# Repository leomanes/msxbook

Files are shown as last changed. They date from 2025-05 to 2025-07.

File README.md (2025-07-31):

# Msxbook side slot
(Msxbook external slot 2 adapter)

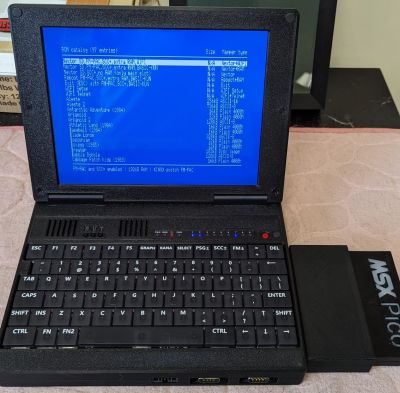
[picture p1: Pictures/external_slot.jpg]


You are welcome to make and sell the adapter to the MSX community if you agree not to change the original files. 
Don't add new text or logos... don't change anything at all and it is all good.

Parts List:

-Main PCB: \
-- F1: 125ma to 375ma fuse (-12v line) \
-- F2: 800ma to 1A fuse (+5v line) \
-- F3: 400ma to 500ma fuse (+12v line) \
-- J1: 2x25 right angle pin header \
-- J2: 50 pin right angle male SCSI connector

***  The fuses are optional but recomended. If you don't want to use them, use a solid wire (old network cables are good donors).

-External PCB: \
-- C1: 100uf to 220uf 25v (optional)\
-- C2: 100uf to 220uf 25v (optional)\
-- C3: 220uf to 470uf 16v (optional)\
-- J1: 50 pin right angle edge connector\
-- J2: 50 pin right angle female SCSI connector

-3D brackets: (The dimentions below are critical. Get the correct ones.) \
--Screws are M2.5 x 5mm\
--Inserts are M2.5 x 2.5 x 3.5 

-Parts Link: \
https://a.aliexpress.com/_mOBWXzN \
https://www.aliexpress.us/item/2255800960638500.html (option: 2X25 50PIN) \
https://www.aliexpress.com/item/3256808357131162.html (option: M2.5x2.5x3.5) \
SCSI connectors: single or pack \
https://www.aliexpress.us/item/3256807779614080.html (option: 50 pin curved female and 50 pin curved male) \
https://a.aliexpress.com/_mt0LCd1 (option: 50 pin curved female and 50 pin curved male)

Tips and tricks: \
*** When soldering the EDGE connector, make sure the distance between the PCB and the connector is between 2mm and 3mm. \
*** The distance between the bottom of the main PCB and the top ot the angled pin header needs to be 7.3mm \
*** Make sure the angled pin header and EDGE connectors are at a nice 90°. Start by solderins pins 1, 2 and 49, 50 and then do a fit test and measure the distance mentioned above. \
*** To insert the pcb into the 3D cart, angle it 45° and insert the left side first ("left" when looking at inside the EDGE where the cart connects) then slide the board in, sitting it flush.

MSX FOREVER !!!

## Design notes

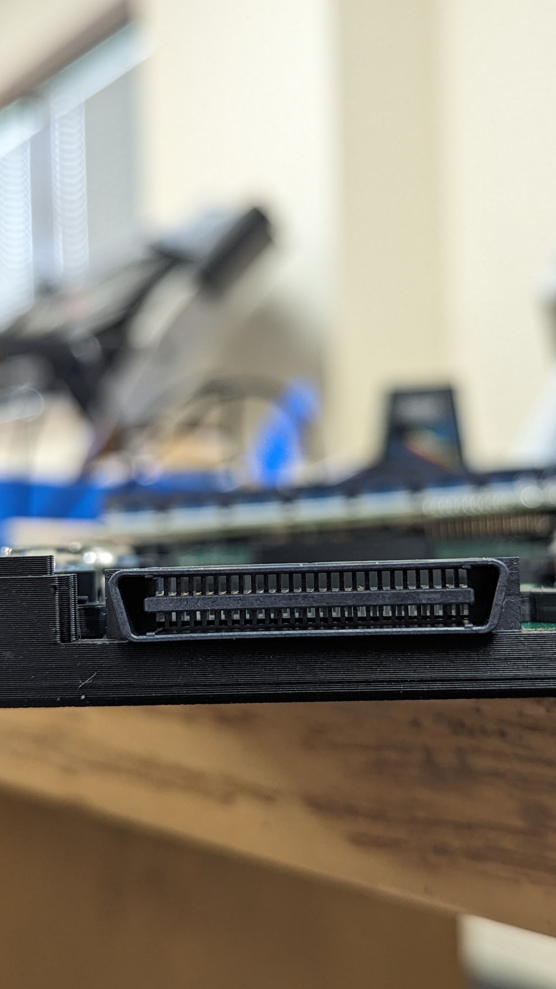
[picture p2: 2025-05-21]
Pictures/pic3.jpg

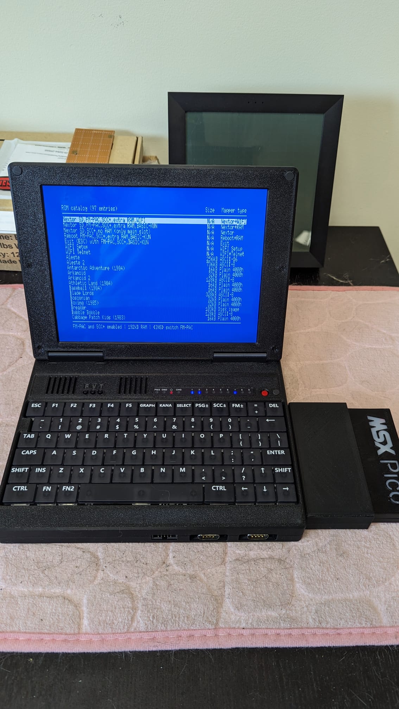
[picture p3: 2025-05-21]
Pictures/pic9.jpg

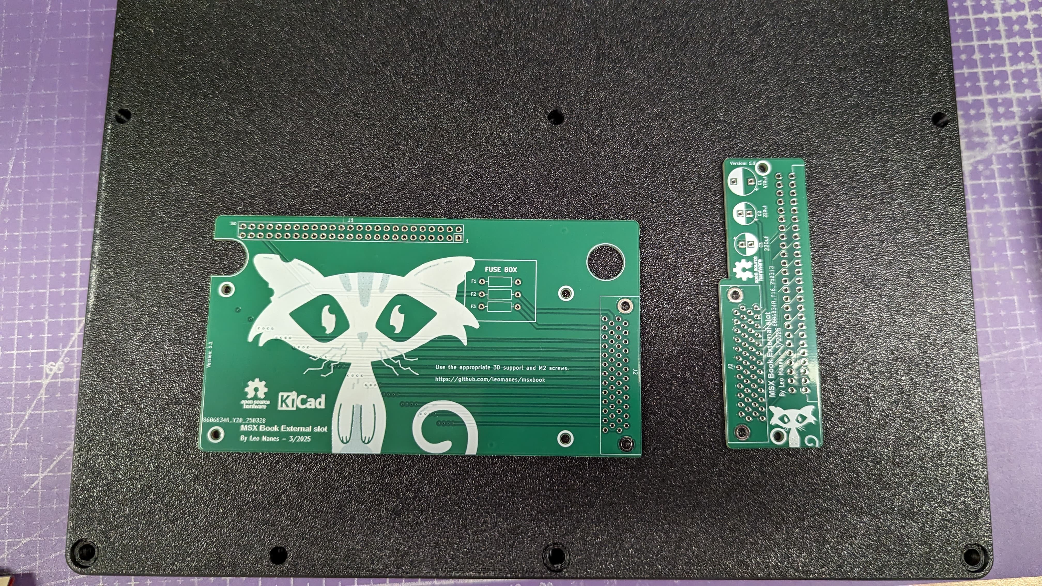
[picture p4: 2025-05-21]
Pictures/pic6.jpg

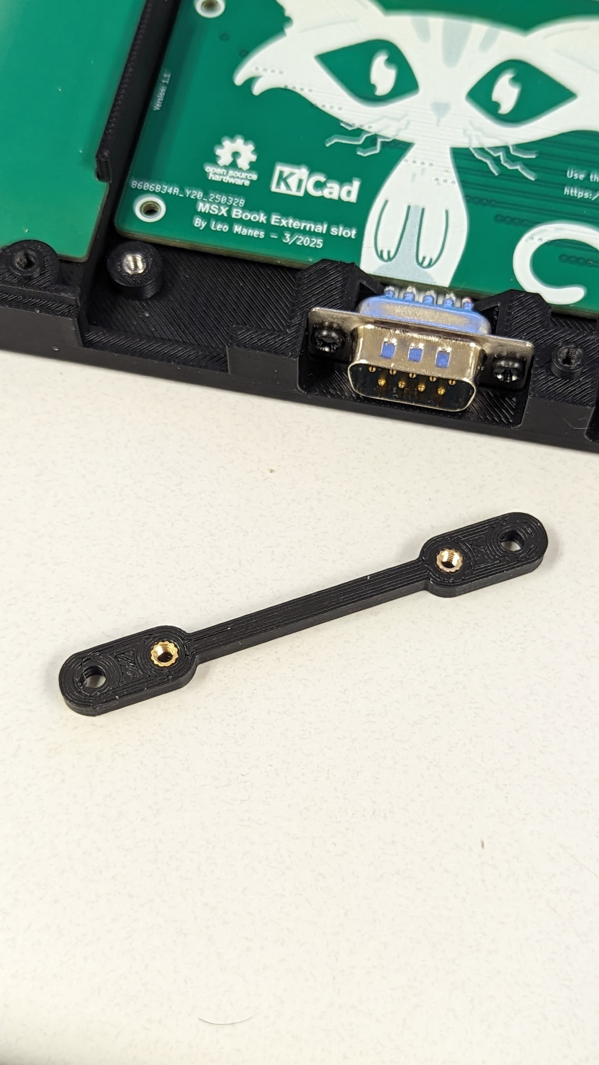
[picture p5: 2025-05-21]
Pictures/pic10.jpg

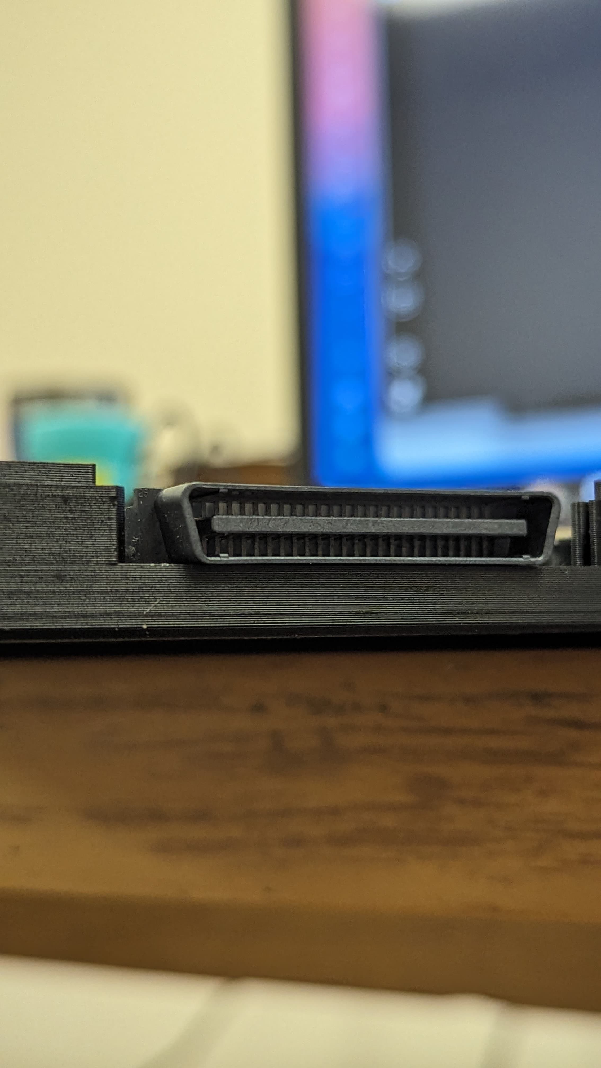
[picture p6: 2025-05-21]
Pictures/pic4.jpg

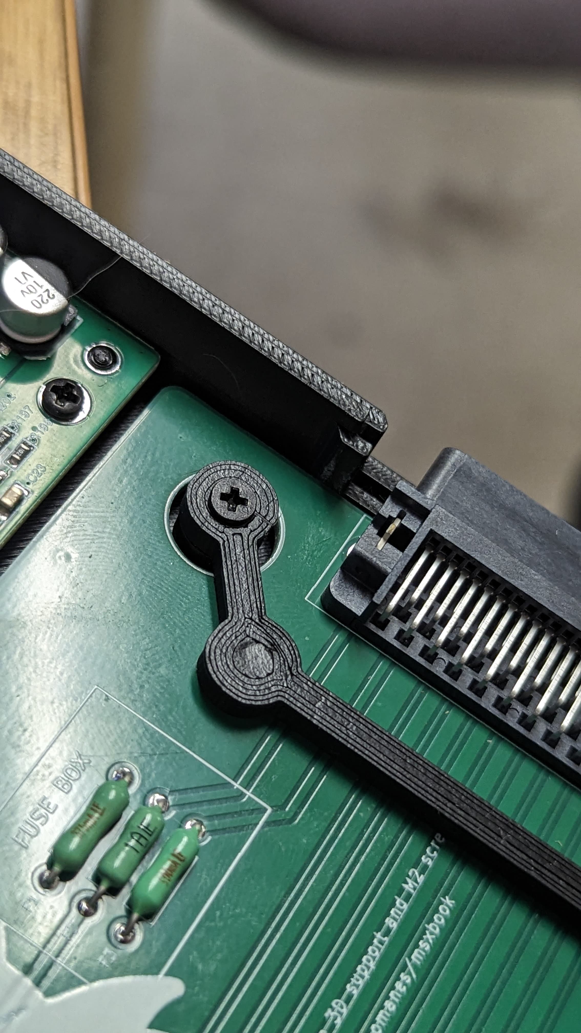
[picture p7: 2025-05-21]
Pictures/pic8.jpg

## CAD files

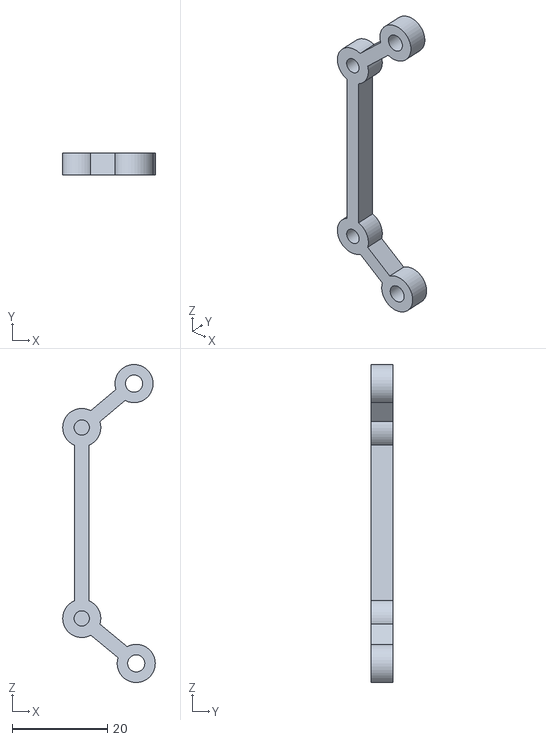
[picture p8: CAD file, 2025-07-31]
3D/Slot2internalSupport2.STL
19.4 x 4.60 x 66.6

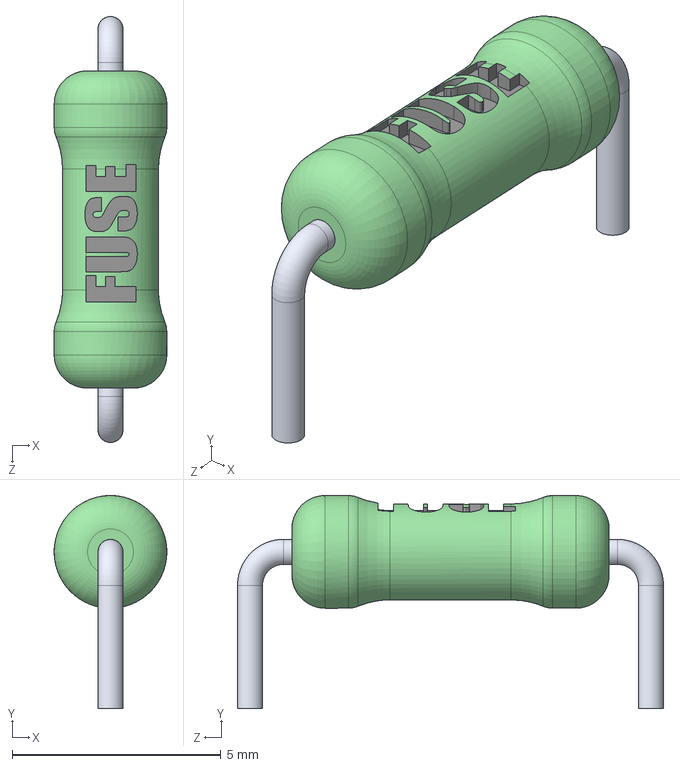
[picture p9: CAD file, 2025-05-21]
Kicad/Main board/FUSE.STEP
2.70 x 5.10 x 10.2 mm

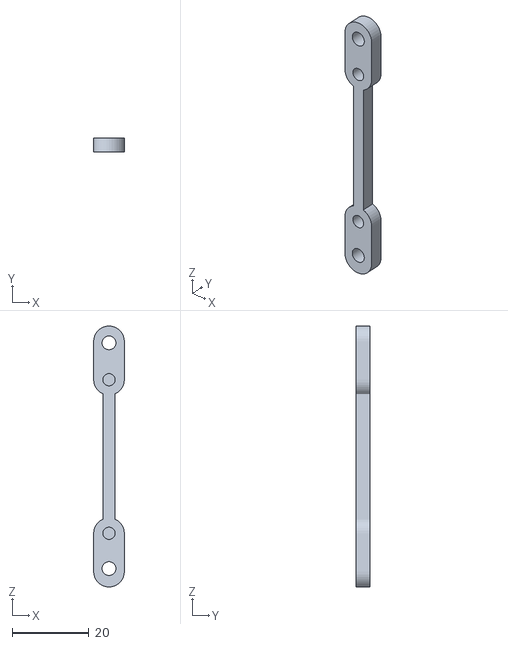
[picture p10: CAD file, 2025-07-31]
3D/Slot2internalSupport1.STL
8.00 x 3.60 x 68.0

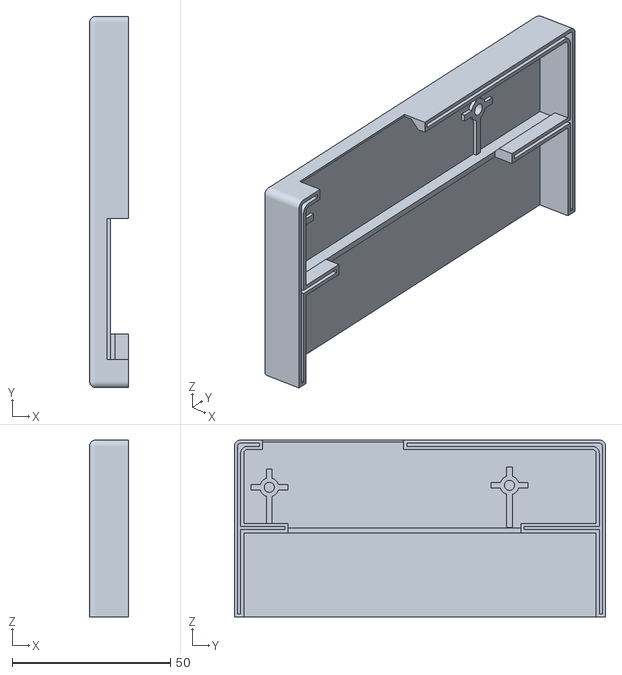
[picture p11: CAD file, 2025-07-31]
3D/Slot2CartBottom.STL
12.4 x 117.5 x 56.0

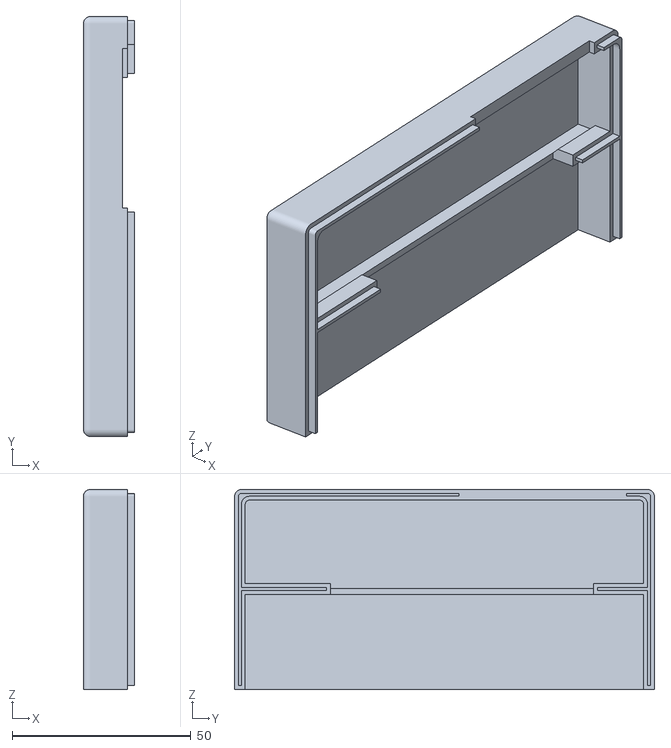
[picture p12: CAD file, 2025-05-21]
3D/Slot2CartTop.STL
14.4 x 117.5 x 56.0

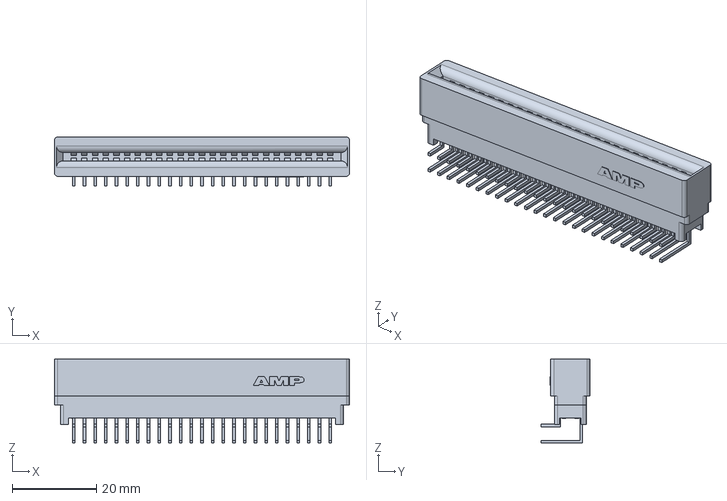
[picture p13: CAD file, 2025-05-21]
Kicad/External board/5532600-2.step
70.1 x 11.6 x 19.9 mm

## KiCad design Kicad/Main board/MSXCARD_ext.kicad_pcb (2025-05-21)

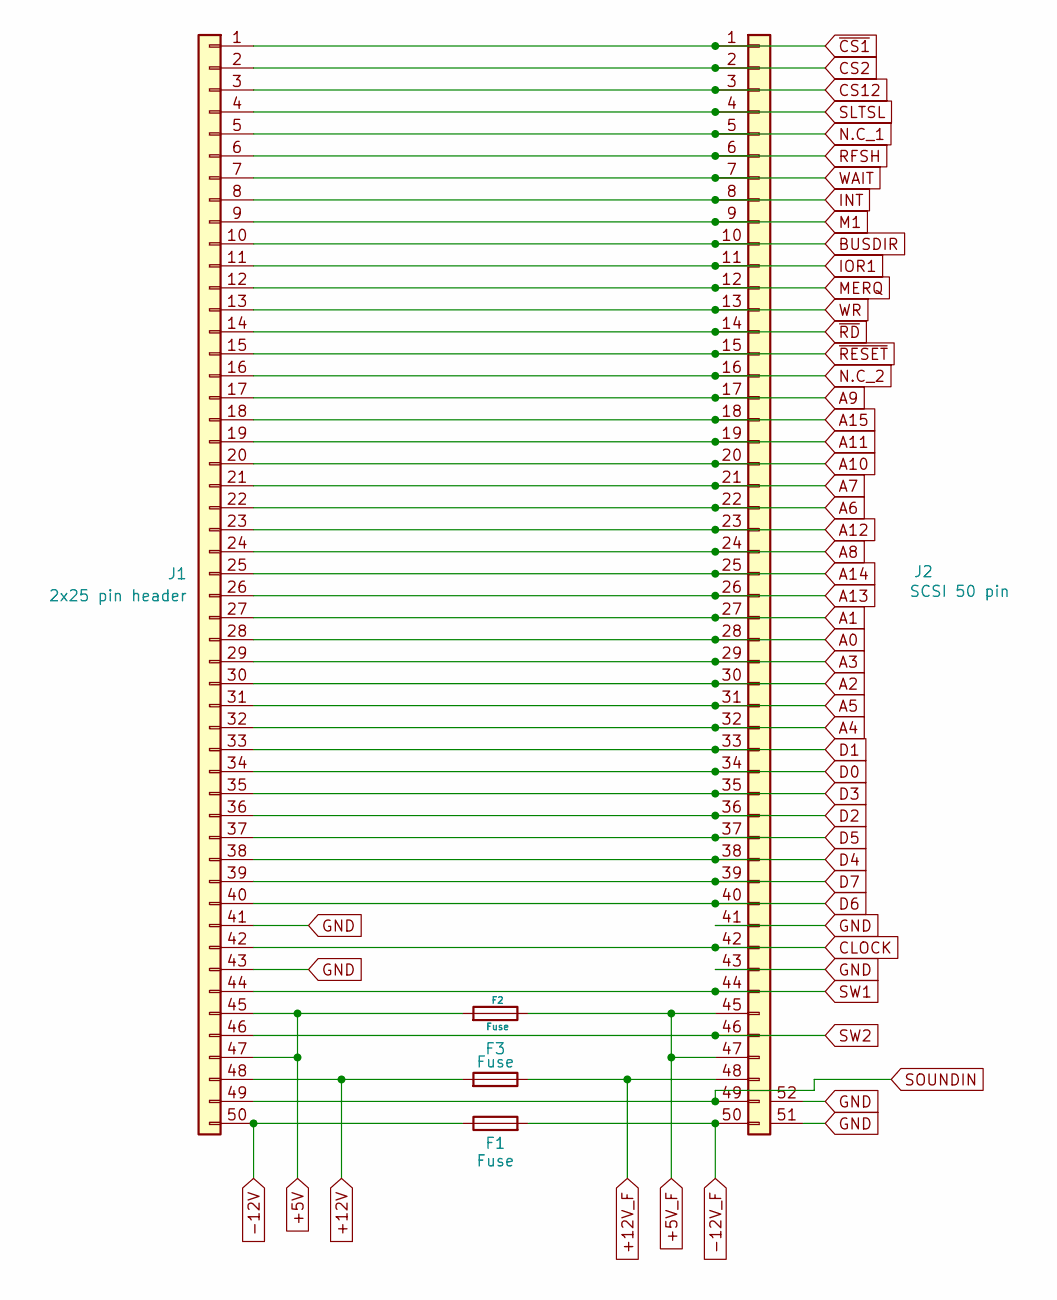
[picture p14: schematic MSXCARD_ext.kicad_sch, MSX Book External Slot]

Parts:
F1, F2, F3: Fuse; R_Axial_DIN0207_L6.3mm_D2.5mm_P10.16mm_Horizontal
J1: 2x25 pin header; PinHeader_2x25_P2.54mm_Vertical_trimmed_2
J2: SCSI 50 pin; SCSI_50_F

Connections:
+5V: F2.2, J1.45, J1.47
+5V_F: F2.1, J2.45, J2.47
+12V: F3.2, J1.48
+12V_F: F3.1, J2.48
-12V: F1.1, J1.50
-12V_F: F1.2, J2.50
A0: J1.28, J2.28
A1: J1.27, J2.27
A2: J1.30, J2.30
A3: J1.29, J2.29
A4: J1.32, J2.32
A5: J1.31, J2.31
A6: J1.22, J2.22
A7: J1.21, J2.21
A8: J1.24, J2.24
A9: J1.17, J2.17
A10: J1.20, J2.20
A11: J1.19, J2.19
A12: J1.23, J2.23
A13: J1.26, J2.26
A14: J1.25, J2.25
A15: J1.18, J2.18
BUSDIR: J1.10, J2.10
CLOCK: J1.42, J2.42
CS2: J1.2, J2.2
CS12: J1.3, J2.3
D0: J1.34, J2.34
D1: J1.33, J2.33
D2: J1.36, J2.36
D3: J1.35, J2.35
D4: J1.38, J2.38
D5: J1.37, J2.37
D6: J1.40, J2.40
D7: J1.39, J2.39
GND: J1.41, J1.43, J2.41, J2.43, J2.51 (Pin_49), J2.52 (Pin_50)
INT: J1.8, J2.8
IOR1: J1.11, J2.11
M1: J1.9, J2.9
MERQ: J1.12, J2.12
N.C_1: J1.5, J2.5
N.C_2: J1.16, J2.16
RFSH: J1.6, J2.6
SLTSL: J1.4, J2.4
SOUNDIN: J1.49, J2.49
SW1: J1.44, J2.44
SW2: J1.46, J2.46
WAIT: J1.7, J2.7
WR: J1.13, J2.13
~CS1: J1.1, J2.1
~RD: J1.14, J2.14
~RESET: J1.15, J2.15

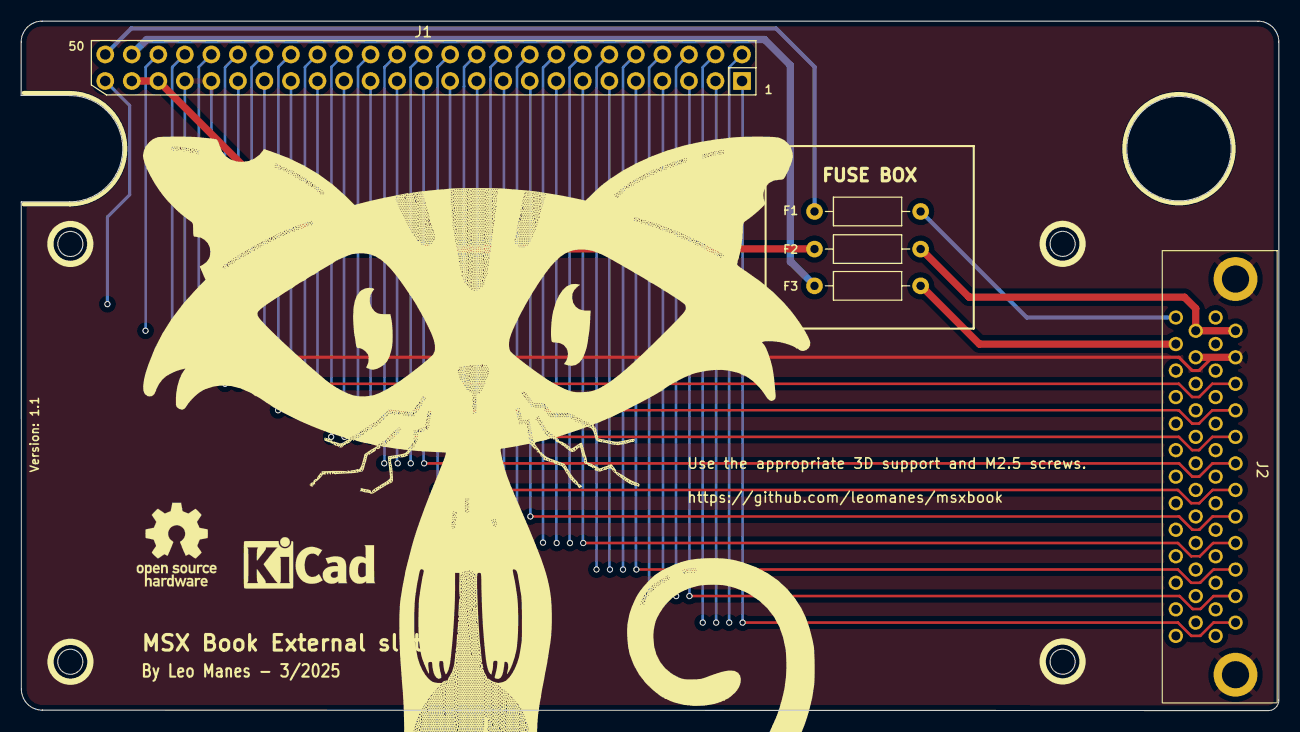
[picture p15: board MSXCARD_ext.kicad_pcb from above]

Board: 4 copper layers, 120.4 x 66.0 mm, 5 parts (0 on the bottom side), 51 nets.

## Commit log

2025-05-21 MSX Book external cart adapter
    [5532600-2.step, FUSE.STEP, MSX book_external_adapter.kicad_pcb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]
2025-07-31 Add files via upload
    Insert holes tightened
    [Slot2CartBottom.STL, Slot2internalSupport1.STL, Slot2internalSupport2.STL]
